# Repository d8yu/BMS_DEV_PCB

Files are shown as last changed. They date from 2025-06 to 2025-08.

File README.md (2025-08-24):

<h1>BMS Development Board</h1>

<h2>Preview</h2>
<h3>PCB Schematic</h3>
PCB_Schematic
<h3>PCB Render</h3>
PCB

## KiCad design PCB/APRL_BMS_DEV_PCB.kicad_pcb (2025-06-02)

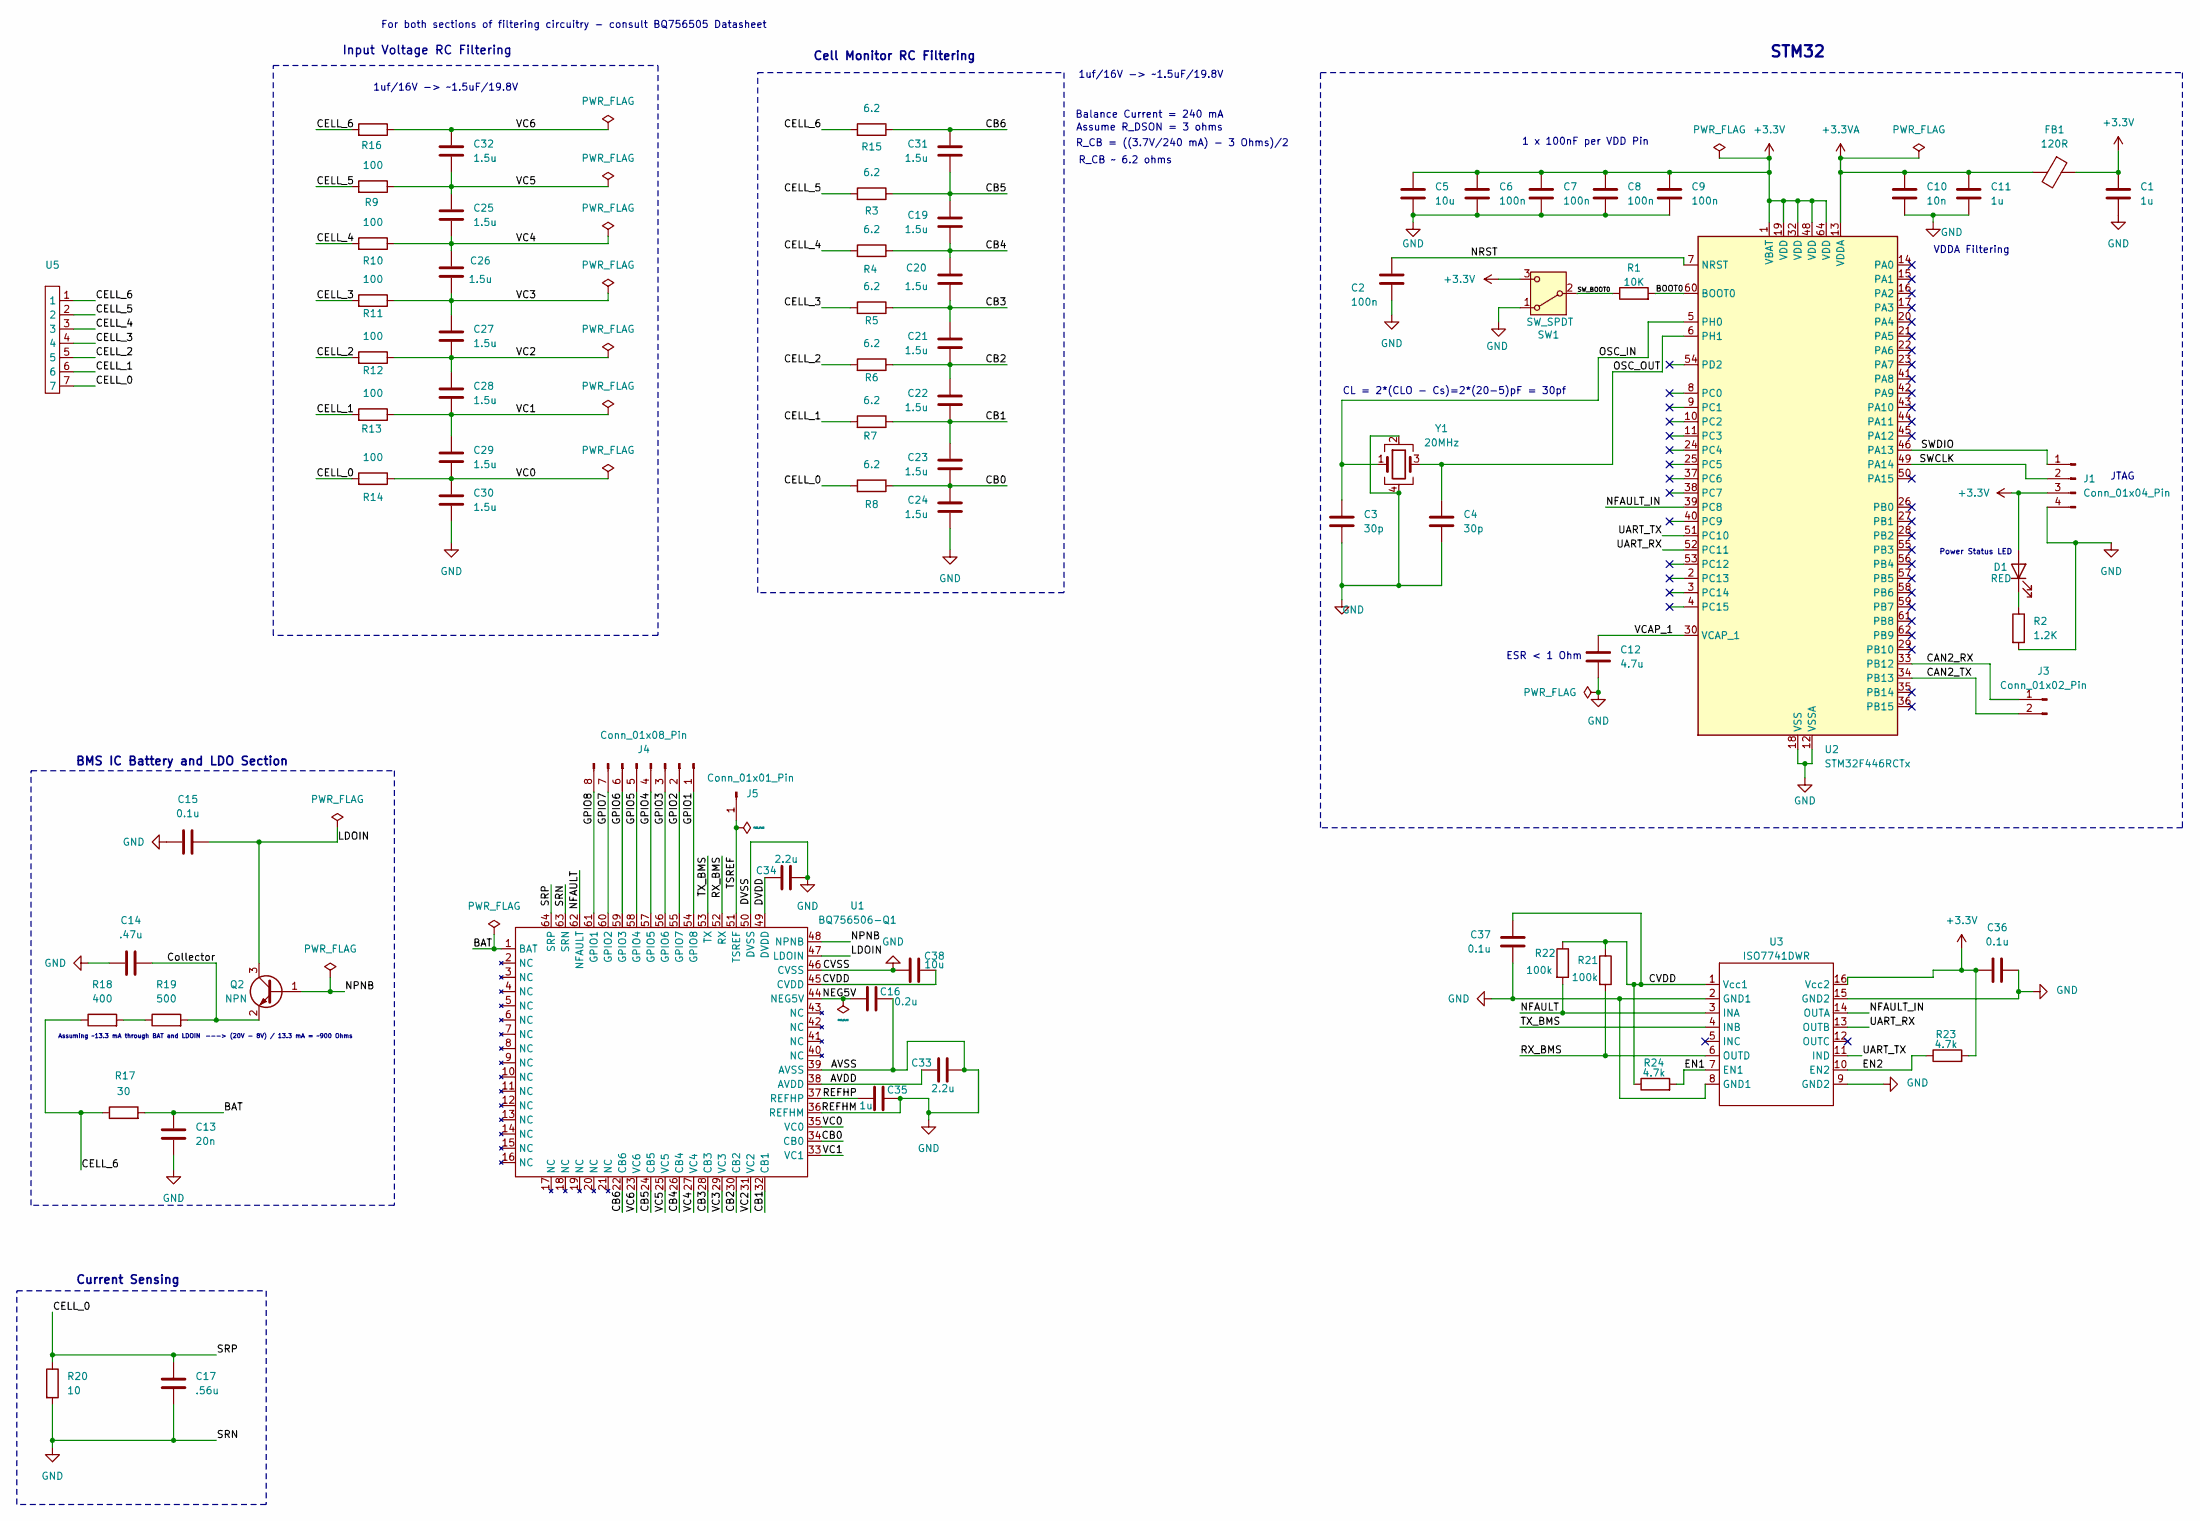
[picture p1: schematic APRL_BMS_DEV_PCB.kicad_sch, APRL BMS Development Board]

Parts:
C1, C11, C35: 1u; C_0603_1608Metric
C2, C6, C7, C8, C9: 100n; C_0603_1608Metric
C3, C4: 30p; C_0603_1608Metric
C5, C38: 10u; C_0603_1608Metric
C10: 10n; C_0603_1608Metric
C12: 4.7u; C_0603_1608Metric
C13: 20n; C_0603_1608Metric
C14: .47u; C_0603_1608Metric
C15, C36, C37: 0.1u; C_0603_1608Metric
C16: 0.2u; C_0603_1608Metric
C17: .56u; C_0603_1608Metric
C19, C20, C21, C22, C23, C24, C25, C26, C27, C28, C29, C30, C31, C32: 1.5u; C_0402_1005Metric
C33, C34: 2.2u; C_0603_1608Metric
D1: RED; LED_0603_1608Metric
FB1: 120R; R_0603_1608Metric
J1: Conn_01x04_Pin; PinHeader_1x04_P2.54mm_Vertical
J3: Conn_01x02_Pin; PinHeader_1x02_P2.54mm_Vertical
J4: Conn_01x08_Pin; PinHeader_1x08_P2.54mm_Vertical
J5: Conn_01x01_Pin; PinHeader_1x01_P2.54mm_Vertical
Q2: NPN; SOT-23
R1: 10K; R_0603_1608Metric
R2: 1.2K; R_0603_1608Metric
R3, R4, R5, R6, R7, R8, R15: 6.2; R_0603_1608Metric
R9, R10, R11, R12, R13, R14, R16: 100; R_0603_1608Metric
R17: 30; R_0603_1608Metric
R18: 400; R_0603_1608Metric
R19: 500; R_0603_1608Metric
R20: 10; R_0603_1608Metric
R21, R22: 100k; R_0603_1608Metric
R23, R24: 4.7k; R_0603_1608Metric
SW1: SW_SPDT; SW_SPDT_PCM12
U1: BQ756506-Q1; LQFP-64_10x10mm_P0.5mm
U2: STM32F446RCTx; LQFP-64_10x10mm_P0.5mm
U3: ISO7741DWR; SOIC-16W_5.3x10.2mm_P1.27mm
U5: S7B-XH-A-1
Y1: 20MHz; Crystal_SMD_3225-4Pin_3.2x2.5mm

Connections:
+3.3V: C1.1, C5.1, C6.1, C7.1, C8.1, C9.1, C36.1, D1.2 (A), FB1.1, J1.3, R23.2, SW1.3 (C), U2.1 (VBAT), U2.19 (VDD), U2.32 (VDD), U2.48 (VDD), U2.64 (VDD), U3.16 (Vcc2)
+3.3VA: C10.1, C11.1, FB1.2, U2.13 (VDDA)
/AVDD: C33.2, U1.38 (AVDD)
/BAT: C13.1, R17.2, U1.1 (BAT)
/BOOT0: R1.2, U2.60 (BOOT0)
/CAN2_RX: J3.1, U2.33 (PB12)
/CAN2_TX: J3.2, U2.34 (PB13)
/CB0: C23.2, C24.1, R8.1, U1.34 (CB0)
/CB1: C22.2, C23.1, R7.1, U1.32 (CB1)
/CB2: C21.2, C22.1, R6.1, U1.30 (CB2)
/CB3: C20.2, C21.1, R5.1, U1.28 (CB3)
/CB4: C19.2, C20.1, R4.1, U1.26 (CB4)
/CB5: C19.1, C31.2, R3.1, U1.24 (CB5)
/CB6: C31.1, R15.1, U1.22 (CB6)
/CELL_0: C17.1, R8.2, R14.2, R20.1, U1.64 (SRP), U5.7
/CELL_1: R7.2, R13.2, U5.6
/CELL_2: R6.2, R12.2, U5.5
/CELL_3: R5.2, R11.2, U5.4
/CELL_4: R4.2, R10.2, U5.3
/CELL_5: R3.2, R9.2, U5.2
/CELL_6: R15.2, R16.2, R17.1, R18.1, U5.1
/CVDD: C37.1, C38.2, R21.1, R22.1, R24.1, U1.45 (CVDD), U3.1 (Vcc1)
/Collector: C14.2, Q2.2 (E), R19.2
/DVDD: C34.1, U1.49 (DVDD)
/EN1: R24.2, U3.7 (EN1)
/EN2: R23.1, U3.10 (EN2)
/GPIO1: J4.1, U1.54 (GPIO8)
/GPIO2: J4.2, U1.55 (GPIO7)
/GPIO3: J4.3, U1.56 (GPIO6)
/GPIO4: J4.4, U1.57 (GPIO5)
/GPIO5: J4.5, U1.58 (GPIO4)
/GPIO6: J4.6, U1.59 (GPIO3)
/GPIO7: J4.7, U1.60 (GPIO2)
/GPIO8: J4.8, U1.61 (GPIO1)
/LDOIN: C15.2, Q2.3 (C), U1.47 (LDOIN)
/NEG5V: C16.2, U1.44 (NEG5V)
/NFAULT: R22.2, U1.62 (NFAULT), U3.3 (INA)
/NFAULT_IN: U2.39 (PC8), U3.14 (OUTA)
/NPNB: Q2.1 (B), U1.48 (NPNB)
/NRST: C2.1, U2.7 (NRST)
/OSC_IN: C3.1, U2.5 (PH0), Y1.1
/OSC_OUT: C4.1, U2.6 (PH1), Y1.3
/REFHP: C35.2, U1.37 (REFHP)
/RX_BMS: R21.2, U1.52 (RX), U3.6 (OUTD)
/SWCLK: J1.2, U2.49 (PA14)
/SWDIO: J1.1, U2.46 (PA13)
/SW_BOOT0: R1.1, SW1.2 (B)
/TSREF: J5.1, U1.51 (TSREF)
/TX_BMS: U1.53 (TX), U3.4 (INB)
/UART_RX: U2.52 (PC11), U3.13 (OUTB)
/UART_TX: U2.51 (PC10), U3.11 (IND)
/VC0: C29.2, C30.1, R14.1, U1.35 (VC0)
/VC1: C28.2, C29.1, R13.1, U1.33 (VC1)
/VC2: C27.2, C28.1, R12.1, U1.31 (VC2)
/VC3: C26.2, C27.1, R11.1, U1.29 (VC3)
/VC4: C25.2, C26.1, R10.1, U1.27 (VC4)
/VC5: C25.1, C32.2, R9.1, U1.25 (VC5)
/VC6: C32.1, R16.1, U1.23 (VC6)
/VCAP_1: C12.1, U2.30 (VCAP_1)
GND: C1.2, C2.2, C3.2, C4.2, C5.2, C6.2, C7.2, C8.2, C9.2, C10.2, C11.2, C12.2, C13.2, C14.1, C15.1, C16.1, C17.2, C24.2, C30.2, C33.1, C34.2, C35.1, C36.2, C37.2, C38.1, J1.4, R2.2, R20.2, SW1.1 (A), U1.36 (REFHM), U1.39 (AVSS), U1.46 (CVSS), U1.50 (DVSS), U1.63 (SRN), U2.12 (VSSA), U2.18 (VSS), U2.31 (VSS), U2.47 (VSS), U2.63 (VSS), U3.2 (GND1), U3.8 (GND1), U3.9 (GND2), U3.15 (GND2), Y1.2, Y1.4
unnamed: D1.1 (K), R2.1
unnamed: R18.2, R19.1

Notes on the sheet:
VDDA Filtering
1uf/16V -> ~1.5uF/19.8V
Balance Current = 240 mA
R_CB = ((3.7V/240 mA) - 3 Ohms)/2
Power Status LED
Assume R_DSON = 3 ohms
JTAG
BMS IC Battery and LDO Section
Assuming ~13.3 mA through BAT and LDOIN
For both sections of filtering circuitry - consult BQ756505 Datasheet
1 x 100nF per VDD Pin
CL = 2*(CLO - Cs)=2*(20-5)pF = 30pf
ESR < 1 Ohm
---> (20V - 8V) / 13.3 mA = ~900 Ohms
STM32
Input Voltage RC Filtering
R_CB ~ 6.2 ohms
Cell Monitor RC Filtering
Current Sensing

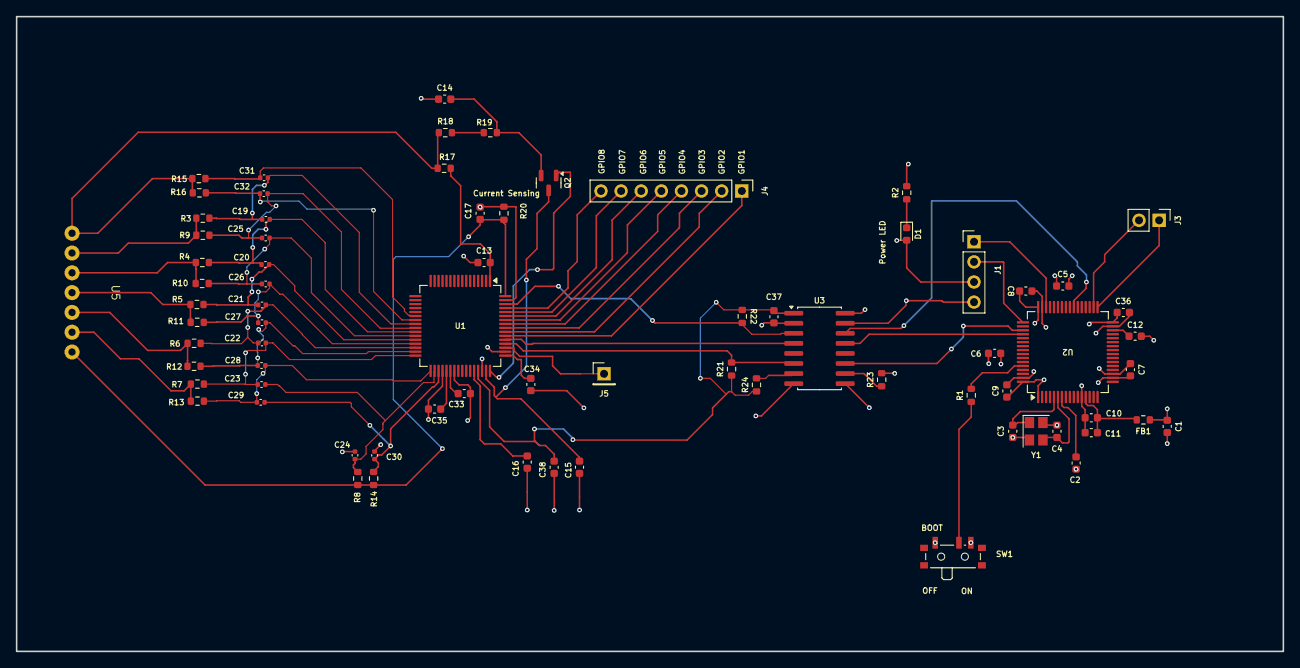
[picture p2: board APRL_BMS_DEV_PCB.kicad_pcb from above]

Board: 4 copper layers, 160.0 x 80.2 mm, 74 parts (0 on the bottom side), 62 nets.

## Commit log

2025-04-24 Added Initial Files
    [APRL_BMS_DEV_PCB.kicad_pcb]
2025-04-24 Initial configuration for STM32
2025-04-27 Changed schematic size to A3
2025-04-28 Added RC Filtering
2025-04-28 Added more labeling to RC filtering
2025-04-28 Added New Net Labels to RC Filters
2025-04-29 Added initial power circuitry
2025-05-03 Added initial footprints and values for caps
    [APRL_BMS_DEV_PCB.kicad_pcb]
2025-05-04 Calculated R and C values, added footprints
2025-05-08 added gnd to isolator
    [APRL_BMS_DEV_PCB.kicad_pcb]
2025-05-10 Edited PCB a little
    [APRL_BMS_DEV_PCB.kicad_pcb]
2025-05-11 Added PCB Traces, fixed Digital Isolator
    [APRL_BMS_DEV_PCB.kicad_pcb]
2025-05-13 Refined some traces
    [APRL_BMS_DEV_PCB.kicad_pcb]
2025-05-15 Fixed TX and RX Trace distances
    [APRL_BMS_DEV_PCB.kicad_pcb]
2025-05-15 Started routing Vias for voltage sensing pins
    [APRL_BMS_DEV_PCB.kicad_pcb]
2025-05-15 Changed trace width for signals to 0.15mm
    [APRL_BMS_DEV_PCB.kicad_pcb]
2025-05-16 Finished sketching traces - save for NPN
    [APRL_BMS_DEV_PCB.kicad_pcb]
2025-05-17 Finished initial trace.
    [APRL_BMS_DEV_PCB.kicad_pcb]
2025-05-17 Fixed silkscreen
    [APRL_BMS_DEV_PCB.kicad_pcb]
2025-06-02 Initial design COMPLETE!
    [APRL_BMS_DEV_PCB.kicad_pcb]
2025-08-24 Organized Files
    [APRL_BMS_DEV_PCB.kicad_pcb, APRL_BMS_DEV_PCB.kicad_sch]
